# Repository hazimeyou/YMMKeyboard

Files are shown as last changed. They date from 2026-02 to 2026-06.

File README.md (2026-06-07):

# YMMKeyboard

YMMKeyboard は、YukkuriMovieMaker 4 (YMM4) と連携する自作キーボードプロジェクトです。

このリポジトリでは、ハードウェア・ファームウェア・PC側処理・YMM4プラグインを一元管理しています。

## 特徴

- RP2040 ベースのコントローラ
- USB HID による入力連携
- CherryMX互換キーに対応
- キーはホットスワップ対応のソケットを実装
- YMM4 を選択してなくても入力操作対応

## 必要環境

- Windows 11
- YukkuriMovieMaker 4
- YMMKeyboard本体
- USB 接続環境

## インストール方法

- プラグイン: リリースリンク
- ファームウェア: リリースリンク

プラグインは`YMMKeyboardPlugin.ymme`を起動してください。
ファームウェアのアップデートは、未定です

## 使用方法

各ドキュメントを参照してください。

- [プラグイン](./ymm-plugin/src/YMMKeyboardPlugin/README.md)

- [ファームウェア](./firmware/src/RP2040TinyUsb/README.md)

## リポジトリ構成

- `hardware/` : 基板・筐体・部品・ハード補足資料
- `firmware/` : マイコン側実装
- `ymm-plugin/` : YMM4 プラグイン本体

## ライセンス

本リポジトリは MIT License です。詳細は [LICENSE](LICENSE) を参照してください。

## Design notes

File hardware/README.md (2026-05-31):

# hardware

キーボード本体のハードウェア関連ファイルです。

## 構成

- `pcb/` : KiCad プロジェクト / Gerber / 製造データ
- `case/` : 筐体設計
- `parts/` : 部品表
- `docs/` : ハード補足資料

## メモ

回路変更時は firmware / plugin 側のキー割り当て仕様も合わせて確認してください。

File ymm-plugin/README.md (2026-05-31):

# ymm-plugin

YukkuriMovieMaker 4 向けプラグイン関連を配置します。

## 構成

- `src/` : プラグイン本体ソース
- `tests/` : テスト
- `libs/` : YMM4 参照 DLL など
- `samples/` : サンプル/補助データ

## 現在の要点

- `YMMT読み込み` で `.ymmt` 読み込みとテンプレート実行の両方に対応
- 設定UIでテンプレート一覧を選択可能
- `TestEvent` は最小動作 (MessageBox) のみ

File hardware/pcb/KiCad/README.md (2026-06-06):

# KiCad

キーボード本体のハードウェアCADファイルです。

## 構成

- `YMMKeyboard/` : 初期型キーボードのKiCadプロジェクトファイルと製造データ
- `YMMKeyboardMX/` : CherryMX互換キー搭載型キーボードのKiCadプロジェクトファイルと製造データ

## メモ

`YMMKeyboard`は安価なキーを使用した初期型キーボードのプロジェクトです。jlcpcbで注文することを前提に100x100mmの基板サイズに収まるように設計しています。

`YMMKeyboardMX`は実際に公開当を想定したCherryMX互換キーを使用したキーボードのプロジェクトです。こちらは使いやすさのため100x100mmを超えてます。

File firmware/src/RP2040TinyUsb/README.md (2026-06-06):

# RP2040 TinyUSB 独自ファーム（C）

このフォルダは `CircuitPython` ではなく、`pico-sdk + TinyUSB` で実装した  
YMMキーボード向けの独自ファームです。

## 現在の実装

- USB CDC（シリアル）出力
- Vendor HID（Report ID=1, 63-byte fixed payload）出力
- 5秒ごとに診断イベント `SW_00` の `P/R` を送信
- 3秒ごとに `HB:<uid>` を CDC に送信

## 前提

- Windows
- CMake 3.13以上
- Ninja（推奨）
- ARM GCC（`arm-none-eabi-gcc`）
- `pico-sdk`

## 自動セットアップ（推奨）

リポジトリ直下で実行:

```powershell
powershell -ExecutionPolicy Bypass -File .\tools\scripts\setup-rp2040-build-env.ps1
```

このスクリプトは以下を実行します。

- `tmp\pico\pico-sdk` を自動取得
- `PICO_SDK_PATH` を自動設定（プロセス内）
- `firmware\src\RP2040TinyUsb\build` を生成

## 自動ビルド（推奨）

```powershell
powershell -ExecutionPolicy Bypass -File .\tools\scripts\build-rp2040-tinyusb.ps1
```

生成物:

- `firmware\src\RP2040TinyUsb\build\ymm_keyboard_fw.uf2`

## 手動ビルド

```powershell
$env:PICO_SDK_PATH="C:\path\to\pico-sdk"
cd firmware\src\RP2040TinyUsb
cmake -S . -B build -G Ninja
cmake --build build
```

## 書き込み

1. RP2040 Zero を `BOOTSEL` でマスストレージ起動
2. `ymm_keyboard_fw.uf2` をドラッグ&ドロップ

## 期待されるPC側挙動

- CDC: `UID` / `HB` / `...:SW_00` が出力される
- HID: `YMMK:<uid>:P:SW_00` / `YMMK:<uid>:R:SW_00` が送信される

## 次の実装予定

- 実機配線に合わせたマトリクススキャン
- ロータリーエンコーダ対応（`SW_36` / `SW_37`）
- デバウンスと押下状態管理

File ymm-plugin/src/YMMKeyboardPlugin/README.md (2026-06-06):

# YMMKeyboardPlugin

YMMKeyboardPlugin は、YMMKeyboard リポジトリ内の YukkuriMovieMaker 4 向けプラグイン本体です。
YMMKeyboard本体の入力と、YMM 内の UI キーボード入力をタイムラインに反映させます。

親ドキュメント: [`../README.md`](../README.md)

## 主な機能

- YMMKeyboard本体やUIからの入力受信とキー割り当て
- 全アイテム（テンプレート）のタイムライン配置
- 自由なレイヤー配置
- タイムラインシーク
- 実機、UIごとのキー割り当て
- 単独キーと複数キー組み合わせの割り当て

## 起動方法
リリースから YMMKeyboardPlugin.ymme をダウンロードし、実行してください。（現在未リリース）
ツールタブに「キーボードプラグイン」というボタンが追加されます。（名称変更予定）

## キー割り当て
キー割り当ては、YMMの設定画面→キーボードプラグイン内の割り当てを開くから行います。

## 設定保存先

設定はプラグイン DLL と同じフォルダー配下に保存されます。

- フォルダー: `settings`
- ファイル: `YMMKeyboardSettings.json`

## メモ

- 仮の名称です。正式名称は未定です。
- 今後の予定
- すべてのアイテム操作とプラグイン間連携を実装予定です。
- YEKB用実行スクリプト（プラグイン）を追加予定です。

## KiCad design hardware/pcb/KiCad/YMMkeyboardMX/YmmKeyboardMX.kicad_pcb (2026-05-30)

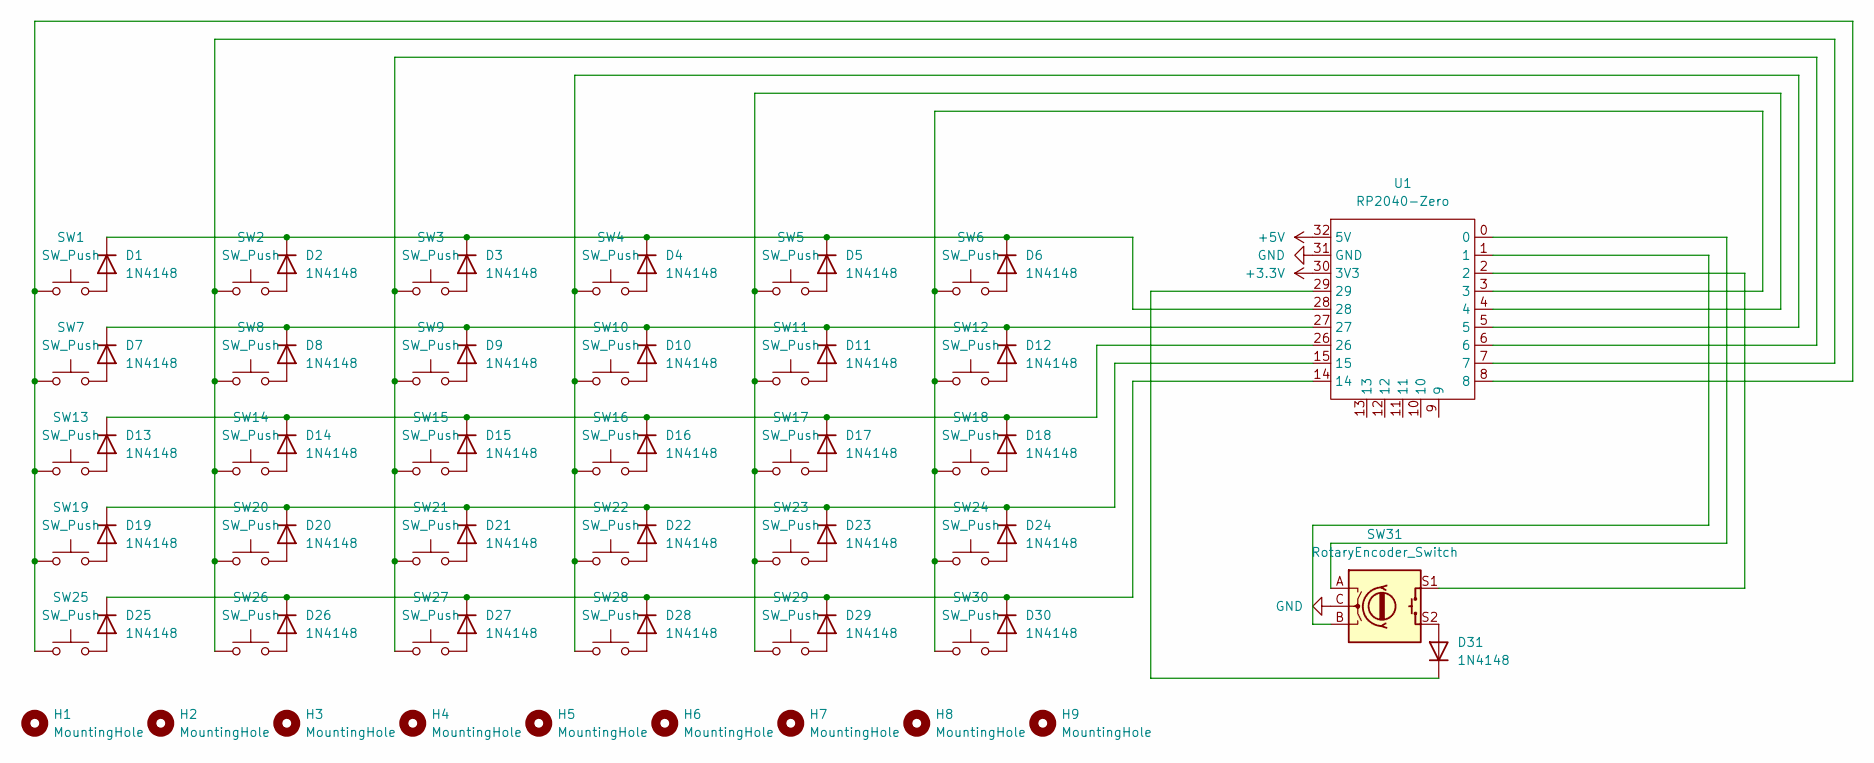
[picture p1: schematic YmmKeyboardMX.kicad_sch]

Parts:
D1, D2, D3, D4, D5, D6, D7, D8, D9, D10, D11, D12, D13, D14, D15, D16, D17, D18, D19, D20, D21, D22, D23, D24, D25, D26, D27, D28, D29, D30, D31: 1N4148; D_SOD-123
H1, H2, H3, H4, H5, H6, H7, H8, H9: MountingHole; MountingHole_2.2mm_M2
SW1, SW2, SW3, SW4, SW5, SW6, SW7, SW8, SW9, SW10, SW11, SW12, SW13, SW14, SW15, SW16, SW17, SW18, SW19, SW20, SW21, SW22, SW23, SW24, SW25, SW26, SW27, SW28, SW29, SW30: SW_Push; CherryMX_Hotswap_1u
SW31: RotaryEncoder_Switch; RotaryEncoder_Alps_EC11E-Switch_Vertical_H20mm
U1: RP2040-Zero; RP2040-ZeroSocket

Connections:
+3.3V: U1.30 (3V3)
+5V: U1.32 (5V)
GND: SW31.C, U1.31 (GND)
unnamed: D1.2 (A), SW1.2
unnamed: D1.1 (K), D2.1 (K), D3.1 (K), D4.1 (K), D5.1 (K), D6.1 (K), U1.28
unnamed: D2.2 (A), SW2.2
unnamed: D3.2 (A), SW3.2
unnamed: D4.2 (A), SW4.2
unnamed: D5.2 (A), SW5.2
unnamed: D6.2 (A), SW6.2
unnamed: D7.2 (A), SW7.2
unnamed: D8.2 (A), SW8.2
unnamed: D9.2 (A), SW9.2
unnamed: D10.2 (A), SW10.2
unnamed: D7.1 (K), D8.1 (K), D9.1 (K), D10.1 (K), D11.1 (K), D12.1 (K), U1.27
unnamed: D11.2 (A), SW11.2
unnamed: D12.2 (A), SW12.2
unnamed: D13.2 (A), SW13.2
unnamed: D13.1 (K), D14.1 (K), D15.1 (K), D16.1 (K), D17.1 (K), D18.1 (K), U1.26
unnamed: D14.2 (A), SW14.2
unnamed: D15.2 (A), SW15.2
unnamed: D16.2 (A), SW16.2
unnamed: D17.2 (A), SW17.2
unnamed: D18.2 (A), SW18.2
unnamed: D19.2 (A), SW19.2
unnamed: D19.1 (K), D20.1 (K), D21.1 (K), D22.1 (K), D23.1 (K), D24.1 (K), U1.15
unnamed: D20.2 (A), SW20.2
unnamed: D21.2 (A), SW21.2
unnamed: D22.2 (A), SW22.2
unnamed: D23.2 (A), SW23.2
unnamed: D24.2 (A), SW24.2
unnamed: D25.2 (A), SW25.2
unnamed: D25.1 (K), D26.1 (K), D27.1 (K), D28.1 (K), D29.1 (K), D30.1 (K), U1.14
unnamed: D26.2 (A), SW26.2
unnamed: D27.2 (A), SW27.2
unnamed: D28.2 (A), SW28.2
unnamed: D29.2 (A), SW29.2
unnamed: D30.2 (A), SW30.2
unnamed: D31.2 (A), SW31.S2
unnamed: D31.1 (K), U1.29
unnamed: SW1.1, SW7.1, SW13.1, SW19.1, SW25.1, U1.8
unnamed: SW4.1, SW10.1, SW16.1, SW22.1, SW28.1, U1.5
unnamed: SW5.1, SW11.1, SW17.1, SW23.1, SW29.1, U1.4
unnamed: SW6.1, SW12.1, SW18.1, SW24.1, SW30.1, U1.3
unnamed: SW2.1, SW8.1, SW14.1, SW20.1, SW26.1, U1.7
unnamed: SW3.1, SW9.1, SW15.1, SW21.1, SW27.1, U1.6
unnamed: SW31.A, U1.0
unnamed: SW31.B, U1.1
unnamed: SW31.S1, U1.2

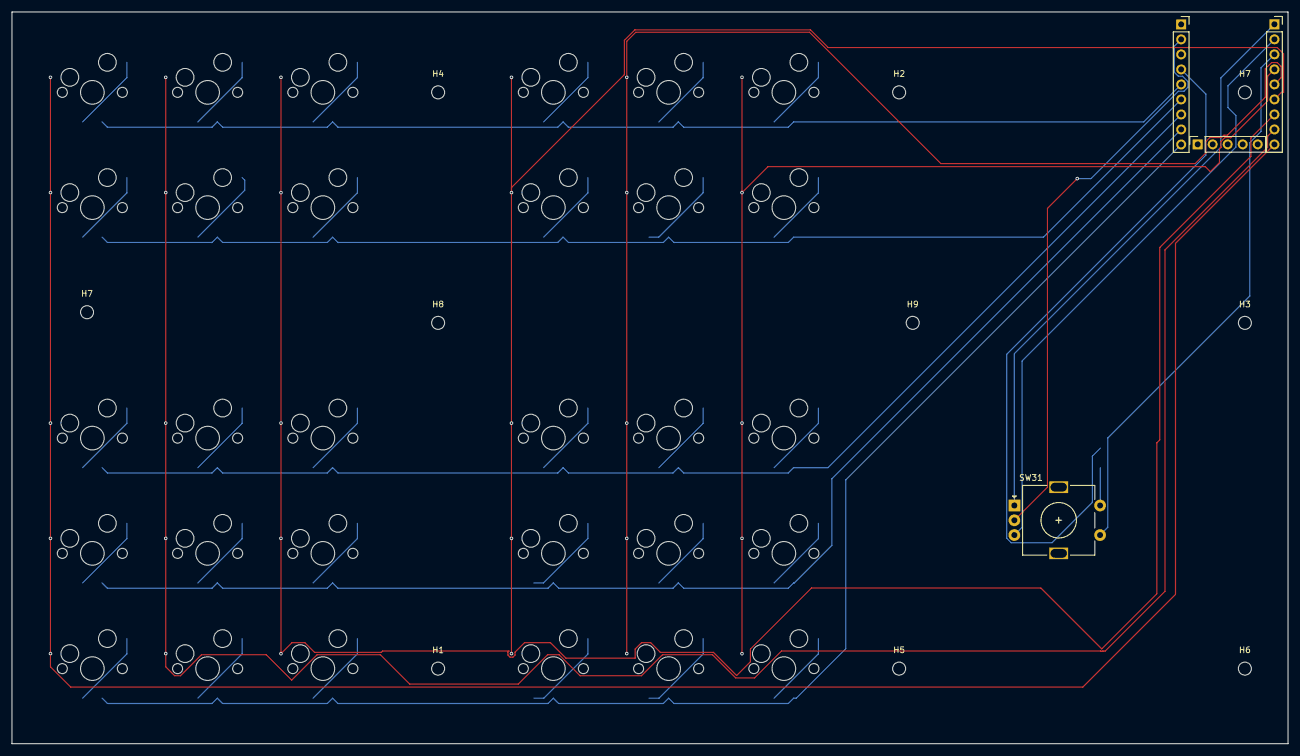
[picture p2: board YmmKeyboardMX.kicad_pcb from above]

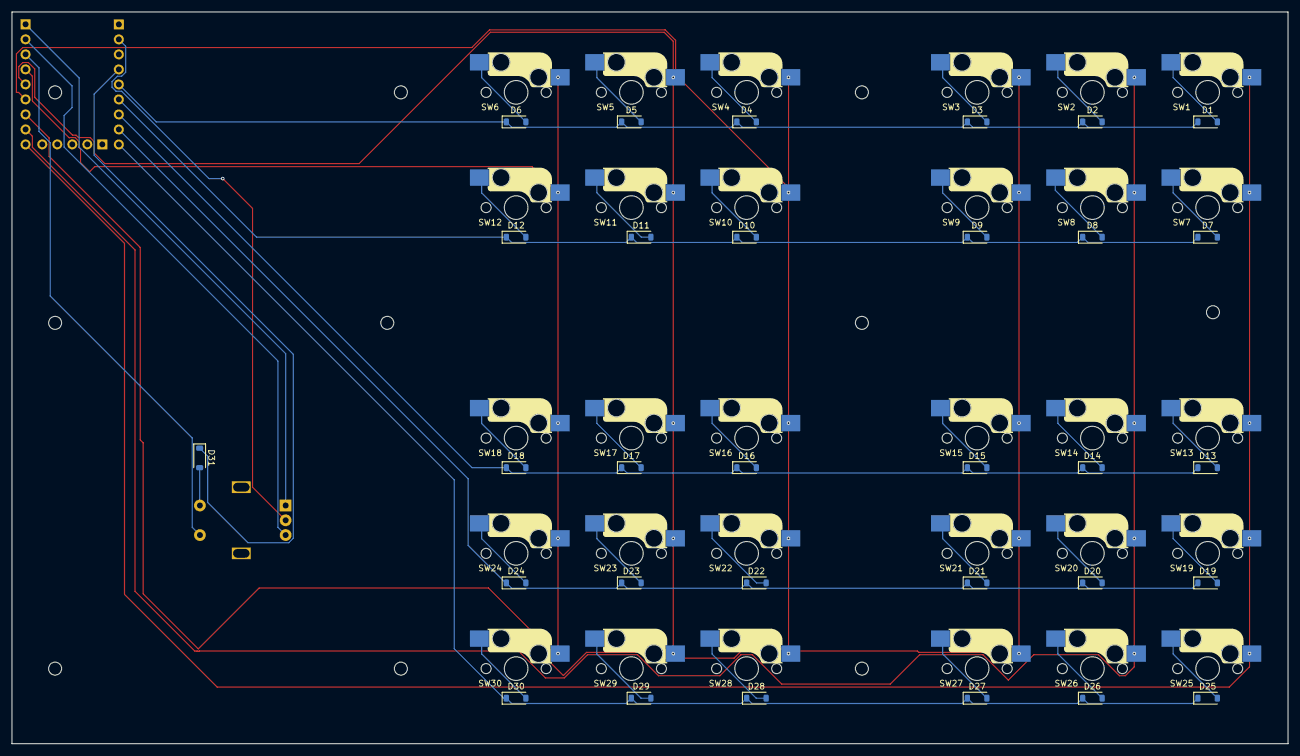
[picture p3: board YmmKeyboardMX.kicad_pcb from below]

Board: 2 copper layers, 215.9 x 123.8 mm, 73 parts (31 on the bottom side), 47 nets.

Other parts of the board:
H7#2: MountingHole; MountingHole_2.2mm_M2

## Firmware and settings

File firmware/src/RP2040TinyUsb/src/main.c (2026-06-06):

#include <stdio.h>
#include <string.h>
#include "pico/stdlib.h"
#include "pico/unique_id.h"
#include "tusb.h"
#include "bsp/board.h"
#include "usb_descriptors.h"

#define FW_ID "YMMKeyboard-RP2040-TinyUSB"
#define FW_VERSION "rotary-detent-quality-rc2"
#define FW_FEATURES "FW_INFO,HID_STATUS,ROTARY_DECODE,ROTARY_STEP,ROTARY_DETENT_QUALITY,ROTARY_HID"
#define FW_BUILD_TIME __DATE__ " " __TIME__
#define MATRIX_COL_COUNT 7
#define MATRIX_ROW_COUNT 6
#define MATRIX_DEBOUNCE_US 20000
#define MATRIX_DIAG_INTERVAL_US 500000
#define MATRIX_FORMAL_REPORT_LENGTH 63u
#define ROTARY_DETENT_THRESHOLD 2
#define ROTARY_IMMEDIATE_MODE 0

static const uint MATRIX_COL_PINS[MATRIX_COL_COUNT] = {2, 8, 7, 6, 5, 4, 3};
static const uint MATRIX_ROW_PINS[MATRIX_ROW_COUNT] = {28, 27, 26, 15, 14, 29};
static const uint ROTARY_A_PIN = 0;
static const uint ROTARY_B_PIN = 1;

static char g_uid_hex[2 * PICO_UNIQUE_BOARD_ID_SIZE_BYTES + 1];
static bool g_hid_last_send_result = false;
static uint32_t g_hid_send_attempt_count = 0;
static uint32_t g_hid_ready_true_count = 0;
static uint32_t g_hid_ready_false_count = 0;
static uint32_t g_hid_report_call_count = 0;
static uint32_t g_hid_report_success_count = 0;
static uint32_t g_hid_report_fail_count = 0;
static uint32_t g_hid_test_sent_count = 0;
static uint32_t g_hid_test_fail_count = 0;
static uint32_t g_matrix_formal_payload_count = 0;
static uint8_t g_fw_info_remaining = 5;
static bool g_fw_info_started = false;
static absolute_time_t g_fw_info_last_emit;
static bool g_usb_mounted = false;
static bool g_usb_suspended = false;
static uint32_t g_mount_count = 0;
static uint32_t g_unmount_count = 0;
static uint32_t g_suspend_count = 0;
static uint32_t g_resume_count = 0;
static char g_usb_event_queue[8][160];
static uint8_t g_usb_event_head = 0;
static uint8_t g_usb_event_tail = 0;
static uint8_t g_usb_event_count = 0;
static bool g_matrix_initialized = false;
static bool g_matrix_last_raw[MATRIX_ROW_COUNT][MATRIX_COL_COUNT];
static bool g_matrix_stable[MATRIX_ROW_COUNT][MATRIX_COL_COUNT];
static absolute_time_t g_matrix_last_change[MATRIX_ROW_COUNT][MATRIX_COL_COUNT];
static absolute_time_t g_matrix_last_diag;
static bool g_row_state_last[MATRIX_ROW_COUNT];
static char g_scan_frame_rows[MATRIX_ROW_COUNT + 1];
static uint g_matrix_scan_column = 0;
static uint8_t g_rev_last_raw[MATRIX_ROW_COUNT][MATRIX_COL_COUNT];
static uint8_t g_rev_stable[MATRIX_ROW_COUNT][MATRIX_COL_COUNT];
static absolute_time_t g_rev_last_change[MATRIX_ROW_COUNT][MATRIX_COL_COUNT];
static bool g_rev_col_state_last[MATRIX_COL_COUNT];
static char g_rev_scan_frame_cols[MATRIX_COL_COUNT + 1];
static uint g_rev_scan_row = 0;
static bool g_rotary_initialized = false;
static uint8_t g_rotary_last_state = 0;
static int8_t g_rotary_accumulator = 0;
static int8_t g_rotary_direction_accumulator = 0;
static absolute_time_t g_rotary_last_diag;
static uint32_t g_rotary_edge_count = 0;
static uint32_t g_rotary_step_cw_count = 0;
static uint32_t g_rotary_step_ccw_count = 0;
static uint32_t g_rotary_invalid_transition_count = 0;
static uint32_t g_rotary_edges_since_step = 0;
static uint32_t g_rotary_deltas_since_step = 0;

static void write_cdc_line(const char *line)
{
  if (!tud_cdc_connected())
    return;

  tud_cdc_write_str(line);
  tud_cdc_write_str("\r\n");
  tud_cdc_write_flush();
}

static void enqueue_usb_event(const char *event)
{
  char line[160];
  snprintf(line, sizeof(line),
           "USB_EVENT %s mounted=%s suspended=%s mountCount=%lu unmountCount=%lu suspendCount=%lu resumeCount=%lu",
           event,
           g_usb_mounted ? "true" : "false",
           g_usb_suspended ? "true" : "false",
           (unsigned long)g_mount_count,
           (unsigned long)g_unmount_count,
           (unsigned long)g_suspend_count,
           (unsigned long)g_resume_count);
  snprintf(g_usb_event_queue[g_usb_event_tail], sizeof(g_usb_event_queue[g_usb_event_tail]), "%s", line);
  g_usb_event_tail = (uint8_t)((g_usb_event_tail + 1) % (uint8_t)(sizeof(g_usb_event_queue) / sizeof(g_usb_event_queue[0])));
  if (g_usb_event_count < (uint8_t)(sizeof(g_usb_event_queue) / sizeof(g_usb_event_queue[0])))
  {
    g_usb_event_count++;
  }
  else
  {
    g_usb_event_head = (uint8_t)((g_usb_event_head + 1) % (uint8_t)(sizeof(g_usb_event_queue) / sizeof(g_usb_event_queue[0])));
  }
}

static void flush_usb_events_if_ready(void)
{
  if (!tud_cdc_connected())
    return;

  while (g_usb_event_count > 0)
  {
    write_cdc_line(g_usb_event_queue[g_usb_event_head]);
    g_usb_event_head = (uint8_t)((g_usb_event_head + 1) % (uint8_t)(sizeof(g_usb_event_queue) / sizeof(g_usb_event_queue[0])));
    g_usb_event_count--;
  }
}

static void write_hid_diag(const char *button, bool pressed, bool hid_ready, uint16_t report_length, uint8_t report_id, bool send_result)
{
  char line[128];
  snprintf(line, sizeof(line),
           "HID_DIAG:button=%s pressed=%s hidReady=%s reportLength=%u reportId=%u sendResult=%s",
           button,
           pressed ? "true" : "false",
           hid_ready ? "true" : "false",
           (unsigned)report_length,
           (unsigned)report_id,
           send_result ? "true" : "false");
  write_cdc_line(line);
}

static void write_hid_status(const char *phase)
{
  char line[320];
  bool hid_ready = tud_hid_ready();
  snprintf(line, sizeof(line),
           "HID_STATUS:%s mounted=%s suspended=%s hidReady=%s mountCount=%lu unmountCount=%lu suspendCount=%lu resumeCount=%lu hidSendAttemptCount=%lu hidReadyTrueCount=%lu hidReadyFalseCount=%lu hidReportCallCount=%lu hidReportSuccessCount=%lu hidReportFailCount=%lu lastSendResult=%s rotaryEdgeCount=%lu rotaryStepCwCount=%lu rotaryStepCcwCount=%lu rotaryInvalidTransitionCount=%lu reportId=%u reportLength=%u descriptorLength=%u",
           phase,
           g_usb_mounted ? "true" : "false",
           g_usb_suspended ? "true" : "false",
           hid_ready ? "true" : "false",
           (unsigned long)g_mount_count,
           (unsigned long)g_unmount_count,
           (unsigned long)g_suspend_count,
           (unsigned long)g_resume_count,
           (unsigned long)g_hid_send_attempt_count,
           (unsigned long)g_hid_ready_true_count,
           (unsigned long)g_hid_ready_false_count,
           (unsigned long)g_hid_report_call_count,
           (unsigned long)g_hid_report_success_count,
           (unsigned long)g_hid_report_fail_count,
           g_hid_last_send_result ? "true" : "false",
           (unsigned long)g_rotary_edge_count,
           (unsigned long)g_rotary_step_cw_count,
           (unsigned long)g_rotary_step_ccw_count,
           (unsigned long)g_rotary_invalid_transition_count,
           (unsigned)REPORT_ID_VENDOR,
           (unsigned)63,
           (unsigned)hid_report_descriptor_len);
  write_cdc_line(line);
}

static void write_hid_status_short(void)
{
  char line[320];
  bool hid_ready = tud_hid_ready();
  snprintf(line, sizeof(line),
           "HID_STATUS ready=%s mounted=%s suspended=%s hidSendAttemptCount=%lu hidReadyTrueCount=%lu hidReadyFalseCount=%lu hidReportCallCount=%lu hidReportSuccessCount=%lu hidReportFailCount=%lu lastSendResult=%s rotaryEdgeCount=%lu rotaryStepCwCount=%lu rotaryStepCcwCount=%lu rotaryInvalidTransitionCount=%lu sendCount=%lu failCount=%lu",
           hid_ready ? "true" : "false",
           g_usb_mounted ? "true" : "false",
           g_usb_suspended ? "true" : "false",
           (unsigned long)g_hid_send_attempt_count,
           (unsigned long)g_hid_ready_true_count,
           (unsigned long)g_hid_ready_false_count,
           (unsigned long)g_hid_report_call_count,
           (unsigned long)g_hid_report_success_count,
           (unsigned long)g_hid_report_fail_count,
           g_hid_last_send_result ? "true" : "false",
           (unsigned long)g_rotary_edge_count,
           (unsigned long)g_rotary_step_cw_count,
           (unsigned long)g_rotary_step_ccw_count,
           (unsigned long)g_rotary_invalid_transition_count,
           (unsigned long)g_hid_send_attempt_count,
           (unsigned long)g_hid_report_fail_count);
  write_cdc_line(line);
}

static void write_matrix_diag(void)
{
  if (!g_matrix_initialized)
    return;

  char line[128];
  snprintf(line, sizeof(line),
           "MATRIX_SCAN cols=%u rows=%u",
           (unsigned)MATRIX_COL_COUNT,
           (unsigned)MATRIX_ROW_COUNT);
  write_cdc_line(line);
}

static void write_row_config(void)
{
  char line[64];
  for (uint row = 0; row < MATRIX_ROW_COUNT; row++)
  {
    snprintf(line, sizeof(line),
             "ROW_CONFIG GP%u INPUT_PULLUP",
             (unsigned)MATRIX_ROW_PINS[row]);
    write_cdc_line(line);
  }
}

static void write_col_config(void)
{
  char line[160];
  for (uint col = 0; col < MATRIX_COL_COUNT; col++)
  {
    snprintf(line, sizeof(line),
             "COL_CONFIG GP%u OUTPUT",
             (unsigned)MATRIX_COL_PINS[col]);
    write_cdc_line(line);
  }
}

static void write_rev_row_config(void)
{
  char line[64];
  for (uint row = 0; row < MATRIX_ROW_COUNT; row++)
  {
    snprintf(line, sizeof(line),
             "REV_ROW_CONFIG GP%u OUTPUT",
             (unsigned)MATRIX_ROW_PINS[row]);
    write_cdc_line(line);
  }
}

static void write_rev_col_config(void)
{
  char line[64];
  for (uint col = 0; col < MATRIX_COL_COUNT; col++)
  {
    snprintf(line, sizeof(line),
             "REV_COL_CONFIG GP%u INPUT_PULLUP",
             (unsigned)MATRIX_COL_PINS[col]);
    write_cdc_line(line);
  }
}

static void write_scan_frame(uint col, const bool row_values[MATRIX_ROW_COUNT])
{
  for (uint row = 0; row < MATRIX_ROW_COUNT; row++)
    g_scan_frame_rows[row] = row_values[row] ? '1' : '0';
  g_scan_frame_rows[MATRIX_ROW_COUNT] = '\0';

  char line[128];
  snprintf(line, sizeof(line),
           "SCAN_FRAME COL=%u ROWS=%s",
           (unsigned)col,
           g_scan_frame_rows);
  write_cdc_line(line);
}

static void write_rev_scan_frame(uint row, const uint8_t col_levels[MATRIX_COL_COUNT])
{
  for (uint col = 0; col < MATRIX_COL_COUNT; col++)
    g_rev_scan_frame_cols[col] = col_levels[col] ? '1' : '0';
  g_rev_scan_frame_cols[MATRIX_COL_COUNT] = '\0';

  char line[128];
  snprintf(line, sizeof(line),
           "REV_SCAN_FRAME ROW=%u COLS=%s",
           (unsigned)row,
           g_rev_scan_frame_cols);
  write_cdc_line(line);
}

static void write_row_edge(uint row, bool old_value, bool new_value)
{
  char line[96];
  snprintf(line, sizeof(line),
           "ROW_EDGE row=%u old=%u new=%u",
           (unsigned)row,
           old_value ? 1u : 0u,
           new_value ? 1u : 0u);
  write_cdc_line(line);
}

static void write_matrix_candidate(uint row, uint col)
{
  char line[96];
  snprintf(line, sizeof(line),
           "MATRIX_CANDIDATE row=%u col=%u",
           (unsigned)row,
           (unsigned)col);
  write_cdc_line(line);
}

static void write_rev_col_edge(uint row, uint col, uint8_t old_value, uint8_t new_value)
{
  char line[112];
  snprintf(line, sizeof(line),
           "REV_COL_EDGE row=%u col=%u old=%u new=%u",
           (unsigned)row,
           (unsigned)col,
           (unsigned)old_value,
           (unsigned)new_value);
  write_cdc_line(line);
}

static void write_rev_matrix_candidate(uint row, uint col)
{
  char line[96];
  snprintf(line, sizeof(line),
           "REV_MATRIX_CANDIDATE row=%u col=%u",
           (unsigned)row,
           (unsigned)col);
  write_cdc_line(line);
}

static void write_rotary_config(void)
{
  char line[64];

  snprintf(line, sizeof(line),
           "ROTARY_CONFIG GP%u INPUT_PULLUP",
           (unsigned)ROTARY_A_PIN);
  write_cdc_line(line);

  snprintf(line, sizeof(line),
           "ROTARY_CONFIG GP%u INPUT_PULLUP",
           (unsigned)ROTARY_B_PIN);
  write_cdc_line(line);
}

static void write_rotary_edge(uint8_t prev_state, uint8_t curr_state)
{
  uint8_t old_a = (prev_state >> 1) & 1u;
  uint8_t old_b = prev_state & 1u;
  uint8_t new_a = (curr_state >> 1) & 1u;
  uint8_t new_b = curr_state & 1u;
  char line[112];
  snprintf(line, sizeof(line),
           "ROTARY_EDGE old=%u new=%u oldA=%u oldB=%u newA=%u newB=%u",
           (unsigned)prev_state,
           (unsigned)curr_state,
           (unsigned)old_a,
           (unsigned)old_b,
           (unsigned)new_a,
           (unsigned)new_b);
  write_cdc_line(line);
}

static void write_rotary_raw(uint8_t a_value, uint8_t b_value)
{
  uint8_t ab = (uint8_t)((a_value << 1) | b_value);
  char line[96];
  snprintf(line, sizeof(line),
           "ROTARY_RAW a=%u b=%u ab=%u",
           (unsigned)a_value,
           (unsigned)b_value,
           (unsigned)ab);
  write_cdc_line(line);
}

static void write_rotary_decode(uint8_t prev_state, uint8_t curr_state, int8_t delta, int8_t accum)
{
  char line[112];
  snprintf(line, sizeof(line),
           "ROTARY_DECODE old=%u new=%u delta=%d accum=%d threshold=%d",
           (unsigned)prev_state,
           (unsigned)curr_state,
           (int)delta,
           (int)accum,
           ROTARY_DETENT_THRESHOLD);
  write_cdc_line(line);
}

static void write_rotary_step(const char *direction, const char *mapped, bool immediate, int8_t delta, int8_t accum_before)
{
  char line[160];
  snprintf(line, sizeof(line),
           "ROTARY_STEP immediate=%s delta=%d direction=%s mapped=%s accumBefore=%d threshold=%d",
           immediate ? "true" : "false",
           (int)delta,
           direction,
           mapped,
           (int)accum_before,
           ROTARY_DETENT_THRESHOLD);
  write_cdc_line(line);
}

static void write_rotary_click_analysis(const char *direction, uint32_t edge_count, uint32_t delta_count)
{
  char line[160];
  snprintf(line, sizeof(line),
           "ROTARY_CLICK_ANALYSIS direction=%s edgeCount=%lu deltaCount=%lu threshold=%d",
           direction,
           (unsigned long)edge_count,
           (unsigned long)delta_count,
           ROTARY_DETENT_THRESHOLD);
  write_cdc_line(line);
}

static bool send_hid_report(const char *label, const char *payload_text, uint16_t payload_length, bool pressed);

static void write_rotary_diag(void)
{
  uint8_t a_value = gpio_get(ROTARY_A_PIN) ? 1u : 0u;
  uint8_t b_value = gpio_get(ROTARY_B_PIN) ? 1u : 0u;
  write_rotary_raw(a_value, b_value);
}

static void init_rotary_input(void)
{
  gpio_init(ROTARY_A_PIN);
  gpio_set_dir(ROTARY_A_PIN, GPIO_IN);
  gpio_pull_up(ROTARY_A_PIN);

  gpio_init(ROTARY_B_PIN);
  gpio_set_dir(ROTARY_B_PIN, GPIO_IN);
  gpio_pull_up(ROTARY_B_PIN);

  g_rotary_last_state = (uint8_t)(((gpio_get(ROTARY_A_PIN) ? 1u : 0u) << 1) | (gpio_get(ROTARY_B_PIN) ? 1u : 0u));
  g_rotary_accumulator = 0;
  g_rotary_direction_accumulator = 0;
  g_rotary_edges_since_step = 0;
  g_rotary_deltas_since_step = 0;
  g_rotary_initialized = true;
  g_rotary_last_diag = get_absolute_time();

  write_rotary_config();
}

static int8_t rotary_transition_delta(uint8_t prev_state, uint8_t curr_state)
{
  static const int8_t delta_table[16] = {
    0, -1, 1, 0,
    1, 0, 0, -1,
    -1, 0, 0, 1,
    0, 1, -1, 0
  };

  return delta_table[((prev_state & 0x03u) << 2) | (curr_state & 0x03u)];
}

static void emit_rotary_tap(const char *mapped, const char *direction, bool immediate, int8_t delta, int8_t accum_before)
{
  write_rotary_step(direction, mapped, immediate, delta, accum_before);

  char press_payload[63] = {0};
  char release_payload[63] = {0};
  snprintf(press_payload, sizeof(press_payload), "%s:P", mapped);
  snprintf(release_payload, sizeof(release_payload), "%s:R", mapped);

  bool press_sent = send_hid_report(mapped, press_payload, MATRIX_FORMAL_REPORT_LENGTH, true);
  {
    char line[160];
    snprintf(line, sizeof(line),
             "ROTARY_STEP_RESULT mapped=%s payload=%s sent=%s",
             mapped,
             press_payload,
             press_sent ? "true" : "false");
    write_cdc_line(line);
  }
  bool release_sent = send_hid_report(mapped, release_payload, MATRIX_FORMAL_REPORT_LENGTH, false);
  {
    char line[160];
    snprintf(line, sizeof(line),
             "ROTARY_STEP_RESULT mapped=%s payload=%s sent=%s",
             mapped,
             release_payload,
             release_sent ? "true" : "false");
    write_cdc_line(line);
  }
}

static void poll_rotary_input(void)
{
  if (!g_rotary_initialized)
    return;

  uint8_t a_value = gpio_get(ROTARY_A_PIN) ? 1u : 0u;
  uint8_t b_value = gpio_get(ROTARY_B_PIN) ? 1u : 0u;
  uint8_t curr_state = (uint8_t)((a_value << 1) | b_value);
  uint8_t prev_state = g_rotary_last_state;

  if (curr_state == prev_state)
    return;

  g_rotary_last_state = curr_state;
  g_rotary_edge_count++;
  g_rotary_edges_since_step++;
  write_rotary_edge(prev_state, curr_state);

  int8_t delta = rotary_transition_delta(prev_state, curr_state);
  write_rotary_decode(prev_state, curr_state, delta, g_rotary_accumulator);
  if (delta == 0)
  {
    g_rotary_invalid_transition_count++;
    g_rotary_accumulator = 0;
    return;
  }

  g_rotary_deltas_since_step++;
  if (g_rotary_direction_accumulator != 0 && ((g_rotary_direction_accumulator > 0 && delta < 0) || (g_rotary_direction_accumulator < 0 && delta > 0)))
  {
    g_rotary_direction_accumulator = 0;
    g_rotary_accumulator = 0;
  }

  g_rotary_direction_accumulator += delta;
  g_rotary_accumulator += delta;
  if (ROTARY_IMMEDIATE_MODE)
  {
    if (delta > 0)
    {
      g_rotary_step_cw_count++;
      int8_t accum_before = g_rotary_accumulator;
      g_rotary_accumulator = 0;
      emit_rotary_tap("SW36", "CW", true, delta, accum_before);
    }
    else
    {
      g_rotary_step_ccw_count++;
      int8_t accum_before = g_rotary_accumulator;
      g_rotary_accumulator = 0;
      emit_rotary_tap("SW37", "CCW", true, delta, accum_before);
    }
    return;
  }
  if (g_rotary_accumulator >= ROTARY_DETENT_THRESHOLD)
  {
    g_rotary_step_cw_count++;
    int8_t accum_before = g_rotary_accumulator;
    g_rotary_accumulator = 0;
    g_rotary_direction_accumulator = 0;
    write_rotary_click_analysis("CW", g_rotary_edges_since_step, g_rotary_deltas_since_step);
    g_rotary_edges_since_step = 0;
    g_rotary_deltas_since_step = 0;
    emit_rotary_tap("SW36", "CW", false, delta, accum_before);
  }
  else if (g_rotary_accumulator <= -ROTARY_DETENT_THRESHOLD)
  {
    g_rotary_step_ccw_count++;
    int8_t accum_before = g_rotary_accumulator;
    g_rotary_accumulator = 0;
    g_rotary_direction_accumulator = 0;
    write_rotary_click_analysis("CCW", g_rotary_edges_since_step, g_rotary_deltas_since_step);
    g_rotary_edges_since_step = 0;
    g_rotary_deltas_since_step = 0;
    emit_rotary_tap("SW37", "CCW", false, delta, accum_before);
  }
}

static void write_matrix_edge(uint row, uint col, bool pressed)
{
  char line[128];
  snprintf(line, sizeof(line),
           "MATRIX_EDGE row=%u col=%u pressed=%s keyId=K_%u_%u",
           (unsigned)row,
           (unsigned)col,
           pressed ? "true" : "false",
           (unsigned)row,
           (unsigned)col);
  write_cdc_line(line);
}

static void write_matrix_key(uint row, uint col, const char *key_id, bool pressed, bool sent)
{
  char line[128];
  snprintf(line, sizeof(line),
           "MATRIX_KEY row=%u col=%u keyId=%s state=%c sent=%s",
           (unsigned)row,
           (unsigned)col,
           key_id,
           pressed ? 'P' : 'R',
           sent ? "true" : "false");
  write_cdc_line(line);
}

static void init_matrix_input(void)
{
  for (uint col = 0; col < MATRIX_COL_COUNT; col++)
  {
    gpio_init(MATRIX_COL_PINS[col]);
    gpio_set_dir(MATRIX_COL_PINS[col], GPIO_OUT);
    gpio_put(MATRIX_COL_PINS[col], 1);
  }

  for (uint row = 0; row < MATRIX_ROW_COUNT; row++)
  {
    gpio_init(MATRIX_ROW_PINS[row]);
    gpio_set_dir(MATRIX_ROW_PINS[row], GPIO_IN);
    gpio_pull_up(MATRIX_ROW_PINS[row]);
  }

  for (uint row = 0; row < MATRIX_ROW_COUNT; row++)
  {
    g_row_state_last[row] = false;
    for (uint col = 0; col < MATRIX_COL_COUNT; col++)
    {
      g_matrix_last_raw[row][col] = false;
      g_matrix_stable[row][col] = false;
      g_matrix_last_change[row][col] = get_absolute_time();
    }
  }

  write_row_config();
  write_col_config();

  g_matrix_last_diag = get_absolute_time();
  g_matrix_initialized = true;
}
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
int main(void)
{
  board_init();
  tusb_init();
  make_uid_hex();
  init_matrix_reverse_input();
  init_rotary_input();

  absolute_time_t last_hb = get_absolute_time();
  absolute_time_t last_status = get_absolute_time();

  while (true)
  {
    tud_task();
    flush_usb_events_if_ready();

    emit_fw_info_if_ready();
    poll_matrix_reverse_input();
    poll_rotary_input();

    if (absolute_time_diff_us(g_matrix_last_diag, get_absolute_time()) >= MATRIX_DIAG_INTERVAL_US)
    {
      g_matrix_last_diag = get_absolute_time();
      write_matrix_diag();
    }

    if (absolute_time_diff_us(last_hb, get_absolute_time()) > 3000000)
    {
      last_hb = get_absolute_time();
      char hb_line[80];
      snprintf(hb_line, sizeof(hb_line), "HB: fw=%s uid=%s", FW_VERSION, g_uid_hex);
      write_cdc_line(hb_line);
    }

    if (absolute_time_diff_us(last_status, get_absolute_time()) > 1000000)
    {
      last_status = get_absolute_time();
      write_hid_status("poll");
      write_hid_status_short();
    }

    if (g_rotary_initialized &&
        absolute_time_diff_us(g_rotary_last_diag, get_absolute_time()) >= 500000)
    {
      g_rotary_last_diag = get_absolute_time();
      write_rotary_diag();
    }

    sleep_ms(1);
  }
}

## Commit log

2026-01-24 .gitattributes、.gitignore、および LICENSE.txt を追加。
2026-01-24 プロジェクトファイルを追加。
    [YMMkeyboard-B_Cu.gbr, YMMkeyboard-B_Mask.gbr, YMMkeyboard-B_Paste.gbr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]
2026-01-24 制限を追加
2026-01-25 プラグインを作成
2026-02-01 キーボードの設計ミスを変更 原因:ダイオードを直列に配置した結果電圧降下した
    [YMMkeyboard.kicad_pcb, YMMkeyboard.kicad_sch, YmmKeyboardMX.kicad_pcb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]
2026-02-01 ファームウェア多分完成
2026-02-01 kicadのバックアップ除外設定追加
2026-02-01 2号機発注データ
    [YMMkeyboard-B_Cu.gbr, YMMkeyboard-B_Mask.gbr, YMMkeyboard-B_Paste.gbr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]
2026-02-03 いったん完成
2026-02-05 1fなら追加されるようになった
2026-02-07 RGBに対応
2026-02-08 なにしたっけ？
2026-02-08 いったんの最終版 ちゃんとシリアル通信で押した（回した）ところを送信できる奴
2026-02-08 とりあえずの完成版 mp3の追加とタイムラインのスクロールができる できないこと comポートの自動指定 mp3のフレーム数の自動指定
2026-02-11 ライセンスとREADMEを追加 READMEはまだ書いてない
2026-02-11 キーボード完成 LED追加するべき？
    [YmmKeyboardMX.kicad_pcb, YmmKeyboardMX.kicad_sch]
2026-02-11 設定画面を追加（昨日は無） ファイルを再構成
2026-02-11 ライセンスとREADME
2026-02-11 UTF-8に変更
2026-02-13 Revert "設定画面を追加（昨日は無）"
    This reverts commit 06e1c955e993fc517d6a8fdb53da2e81051d020f.
2026-02-19 3号機の発注
    [YmmKeyboardMX-B_Cu.gbr, YmmKeyboardMX-B_Mask.gbr, YmmKeyboardMX-B_Paste.gbr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]
2026-02-19 3号機の発注（忘れてた）
2026-02-19 3号機のcadデータ
    [YmmKeyboardMX.kicad_pcb, YmmKeyboardMX.kicad_sch]
2026-02-19 テストボードを追加 MXキー用ホットスワップソケットとダイオードなどの干渉をテストするのに使います
    [testboard.kicad_pcb, testboard.kicad_sch]
2026-02-19 ライセンス関連
2026-02-21 テスト用キーボード（途中）
    [testboard.kicad_pcb, testboard.kicad_sch]
2026-02-23 3号機発注
    [YmmKeyboardMX-B_Cu.gbr, YmmKeyboardMX-B_Mask.gbr, YmmKeyboardMX-B_Paste.gbr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]
2026-02-26 フォルダ分けとUI大幅変更
2026-02-26 CAD系
    [YmmKeyboardMX.kicad_pcb]
2026-02-27 キーボードの内部番号とUIの名部番号を見るためのクラス作成
2026-02-28 キー配置の統一完了
2026-02-28 設定追加（途中）
2026-02-28 開発PCの追加によるプロファイル追加と 不足していたライブラリ追加
2026-03-01 初期化失敗の修正
2026-03-02 設定関連
2026-03-10 YMMキーボード: 複数ポート/UID対応・割り当てUI刷新
    複数COMポート・複数デバイスUIDの同時管理に対応し、起動時自動接続や既知UIDリストを設定可能に。
    UIDごとにスイッチ割り当てを編集できる専用ウィンドウを追加し、アクションやパラメータの個別設定・テスト実行が可能に。
    設定画面を刷新し、COMポート選択・自動接続・手動テストUID選択・割り当て編集のUIを大幅拡張。
    設定保存形式をUID/スイッチ単位のJSONに変更し、永続化と正規化処理を追加。
    割り当てアクションは拡張性の高い方式にリファクタリングし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
2026-03-11 キーボード割り当てをUI/実機UIDで分離・機能拡張
    キーボード割り当て設定を「UIキーボード」と「実機UID」ごとに個別管理できるよう大幅リファクタリングを実施。設定画面・割り当てウィンドウのUIも「対象」選択方式に変更し、説明文も整理。割り当て可能なアクションに「フレーム送り/戻し」を追加し、タイムライン操作が可能に。設定保存形式も新構造に対応し、全体的な命名や設計を整理・改善。
2026-03-11 プロジェクト構成・名前空間・UIを大規模リファクタリング
    MVVMパターンに沿ってModels/Actions/Views/Mapping等の名前空間・ディレクトリにクラスを再配置し、役割ごとに整理。KeyboardViewのボタンイベントを集約し、SwitchLayout/AssignmentItem等のモデルも分離。UI XAMLもViews配下に統一し、設定画面はYMMKeyboardSettingsPanelに一本化。CreateDefault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
2026-03-11 キーボード割り当て画面のUIを2ペイン方式に刷新
    従来のDataGridによる一覧編集から、左側に仮想キーボード、右側に選択中キーの詳細編集パネルを配置した2ペインUIに大幅リニューアルしました。各キーの割り当て状況が視覚的に分かりやすくなり、選択・編集・テスト実行が直感的に行えるようになりました。UIの配色や余白も調整し、操作性・可読性を向上させています。関連するイベントハンドラや状態管理ロジックも追加しています。
2026-03-11 複数キー組み合わせ割り当て・実行機能を追加
    キーボードプラグインに複数キー同時押し（コンビネーション）によるアクション割り当て・実行機能を追加しました。設定画面・実行画面ともに複数キー編集/実行モードを実装し、設定保存・UI・内部処理を大幅に拡張。単独キーと組み合わせキーの両方に柔軟なカスタマイズが可能となりました。
2026-03-12 YMMTカタログ読込機能追加＆UIリファイン
    YMM4プロジェクト(.ymmt)のcatalog.jsonを読み込む新機能（LoadYmmtCatalogAction）を追加し、テンプレートやアイテム情報のサマリー表示・プラグインフォルダへの保存に対応。YmmtCatalogLoaderやデータモデルも新規実装。キーマッピング・設定・キーボード各画面のXAMLをリファインし、余白・配色・フォント・ボタンサイズ等を調整、選択時の色をWindo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
2026-03-13 README.md の更新
2026-03-13 YM4カタログ読込の例外処理強化＆UI日本語化修正
    LoadYmmtCatalogAction.csで例外処理を強化し、各種エラー時のメッセージ表示を改善しました。また、YmmtCatalogLoader.csでint変換時のオーバーフロー対策を追加。KeyboardView.xamlおよびYMMKeyboardSettingsPanel.xamlの日本語UIテキストの文字化けを修正し、説明文やボタン名も分かりやすく日本語化しました。不要な旧実装コードも削除しています。
2026-03-13 YMMTテンプレートのタイムライン自動インポート対応
    YMMT(.ymmt)ファイル読み込み時に、テンプレート内アイテムをタイムラインへ自動インポートする機能を追加。不明な型やファイル欠損時はスキップし、インポート結果をダイアログで表示。アクション名を日本語化し、「ymmt読み込み」選択時のみパラメータ欄にファイル参照ボタンを表示するなど、設定UIの利便性も向上。
2026-03-13 YMMTインポート時のfps差異対応と設定保存の改善
    YMMTカタログインポート時、テンプレートとタイムラインのfps差異を自動で補正し、アイテムのフレーム位置・長さをスケーリングするよう変更しました。fps取得処理やスケーリング用メソッドを追加し、タイミングのズレを防止します。また、KeyboardMappingWindowでウィンドウクローズ時に選択状態を保存するようOnClosingを実装しました。
2026-03-13 アクション名の正規化とFPS処理の精度向上
    アクション名を日本語・英語混在から英語表記に統一し、NormalizeActionNameメソッドで設定・UI・内部処理の一貫性を確保しました。旧日本語設定ファイルとの互換性も維持されます。また、FPS値の型をdouble化し、取得・計算・表示の精度を向上させました。これにより、設定ファイルやUIの互換性・信頼性が向上しています。
2026-03-16 UIレイアウトのコンパクト化と設定保存処理の強化
    UI各画面のサイズ・マージン・フォント等を調整し、よりコンパクトで見やすいレイアウトに変更。KeyboardAction, LegacyKeyboardViewModel に UndoRedoManager フィールドと未使用警告抑制を追加。RelayCommand の非同期コマンド対応を改善。YMMKeyboardSettings でスレッドセーフな保存、一時ファイル経由、ディープコピーによる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
2026-04-13 キーボードの制御部分を自作したい
    [YMMkeyboardRP.kicad_pcb, YMMkeyboardRP.kicad_sch]
2026-04-13 主要な配線終わった ピンにどうやって配線するんや
    [YMMkeyboardRP.kicad_pcb]
2026-05-24 rp2040の独自実装を検討
    [YMMkeyboardRP.kicad_pcb, YMMkeyboardRP.kicad_sch]
2026-05-24 ねじを締めたときに断線しそうなので修正
    [YmmKeyboardMX.kicad_pcb]
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2026-05-24 ライセンスの修正
2026-05-29 エンコーダ入力の安定化と切断時状態クリアを修正し検証ツールを追加
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2026-05-29 配布DLLを必要最小限に整理し日本語文言とアクション名互換を修正
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2026-05-29 表示文言の日本語化と文字化けの残りを修正
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2026-05-29 実機受信行の正規化とUID検証を追加し不正UID混入による無効化を修正
2026-05-30 chore: reorganize repository files
    [YMMkeyboard-B_Cu.gbr, YMMkeyboard-B_Mask.gbr, YMMkeyboard-B_Paste.gbr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]
2026-05-30 test: add unit tests for mapping and switch layout
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2026-05-30 レビュー指摘対応: 文字化け修正と安定性改善
2026-05-31 Add template CreateItemsAsync probe to TestEvent
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2026-06-02 fix: replace obsolete hidsharp device properties
2026-06-03 feat: add standalone hid console probe
2026-06-04 docs: finalize reverse matrix scan direction
    [main.c]
2026-06-04 fix: align formal matrix payload and plugin input path
    [main.c]
2026-06-05 fix: harden assignment saves and rotary payload contract
    [main.c]
2026-06-06 リポジトリ整理
    [YmmKeyboardMX-B_Cu.gbr, YmmKeyboardMX-B_Mask.gbr, YmmKeyboardMX-B_Paste.gbr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]
2026-06-06 ガーバデータを削除
    [YMMkeyboard-B_Cu.gbr, YMMkeyboard-B_Mask.gbr, YMMkeyboard-B_Paste.gbr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]
2026-06-06 完全オリジナルのRP2040実装版とテスト基板を削除
    [YMMkeyboardRP.kicad_pcb, YMMkeyboardRP.kicad_sch, testboard.kicad_pcb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]
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2026-06-07 feat: add keyboard mapping filter
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2026-06-07 バージョン抽出を修正
2026-06-07 Prepare Package Folder のコピー元を publish\plugin に変更
2026-06-07 Fix pico-sdk submodule fetch in release workflow
